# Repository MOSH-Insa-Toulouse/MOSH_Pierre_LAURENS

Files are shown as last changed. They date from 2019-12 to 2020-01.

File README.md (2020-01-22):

# Projet Smart Device
# MICRO-CONTROLEURS ET OPEN-SOURCE HARDWARE:
# Projet de Construction d'un capteur de gaz 
>LAURENS [Pierre](mailto:plaurens@etud.insa-toulouse.fr) - TOUZANI Ismail - Krishna Sujan

<a href="./README_EN.md">Version Anglaise</a>

Ce projet, faisant partie du Master 5ISS de l'INSA Toulouse, a été developpé dans le but de créer un capteur de gas intelligent capable de détecter plusieurs types de gas qui pourront être dangereux pour la santé humaine.
Après avoir construit le capteur dans l'atelier AIME de l'INSA, il sera donc nécessaire de le régler pour en extraire les informations utiles: cela se fera grâce au logiciel LTSpice IV pour la partie éléctronique analogique. Ensuite, et afin de récupérer les données du capteur et les communiquer à travers le réseau LoRA, on utilisera une carte Arduino Uno et une puce RN2483. Enfin, nous utiliserons le logiciel KiCAD pour effectuer le schéma adéquat du câblage entre les différents composants.

# Contenu du Projet
Le projet est constitué des répertoires suivants:
-   **Mosh (Arduino IDE)**: Contient les fichiers des tps effectués en utilisant l'IDE d'Arduino ainsi que les fichiers du projet.

-   **KiCAD**: Contient les fichiers nécessaires à la réalisation du PCB.
Ce fichier est composé de 3 dossiers.
    - **Projet Kicad** : contenant la première version de notre projet.
    - **Projet Kicad plan de masse** : contenant le même projet que le fichier ci-dessus mais avec la réalisation du plan de masse.
    - **Projet Kicad Aime plan de masse** : contenant le PCB du capteur de Gaz réalisé dans les locaux du AIME.

-   **LTSpice**: Contient les fichiers nécessaires à la partie éléctronique analogique.

-  **Manufacturing_Kicad**: Dossier contenant le fichier de création de la carte.

### Partie collection de données et communication LoRA: 
Dans cette partie, nous avons testé la collection de données et communication LoRA avec un capteur de test:

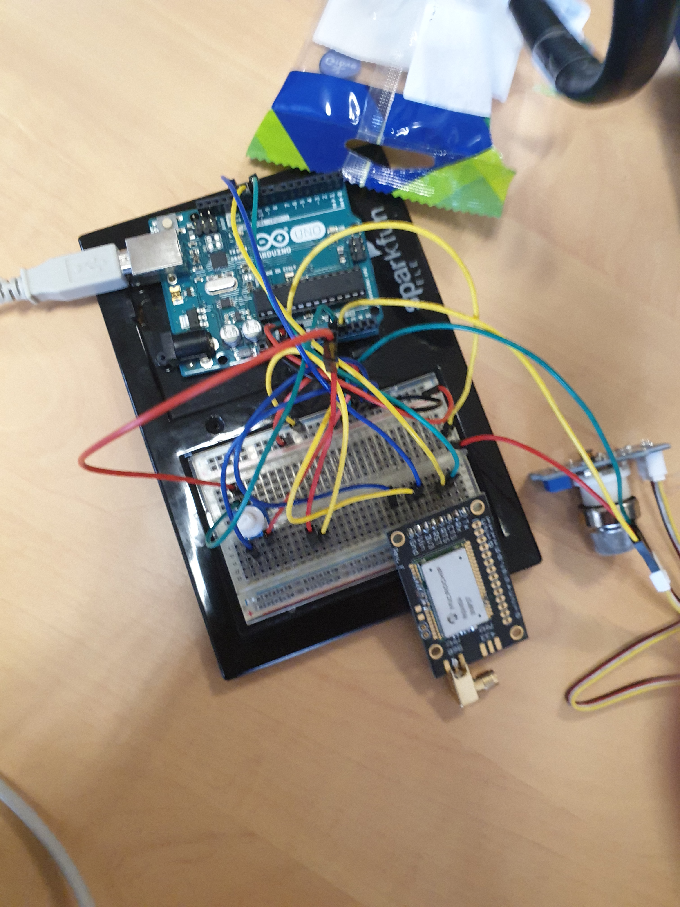
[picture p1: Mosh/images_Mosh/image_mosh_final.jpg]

Ci-dessus l'image du montage permettant d'interconnecter le module LoRa, l'Arduino UNO et le capteur de Gaz.
Ci-dessous une série d'images montrant le résultat de notre montage avec la réception et l'envoi de la valeur du capteur.

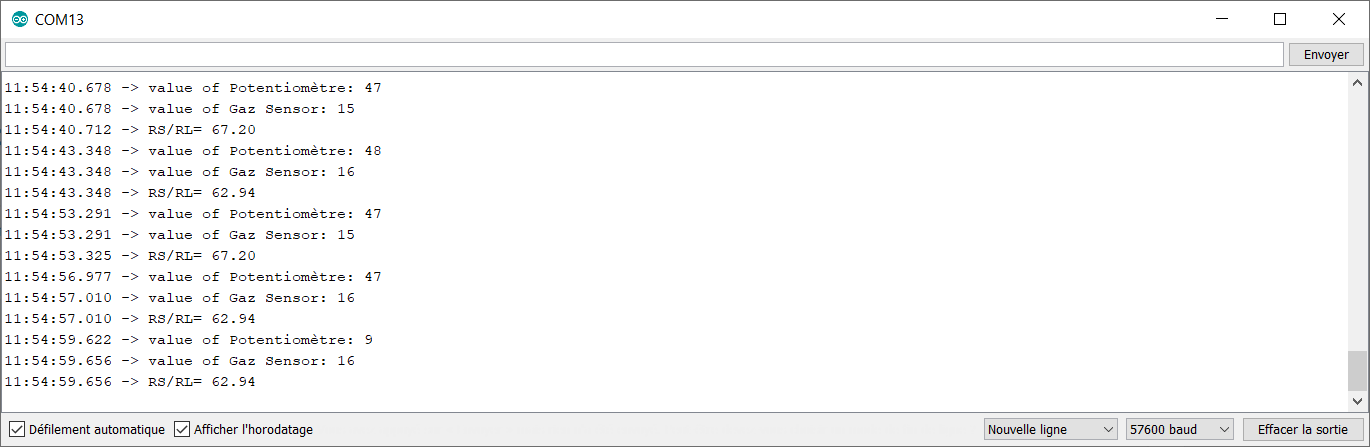
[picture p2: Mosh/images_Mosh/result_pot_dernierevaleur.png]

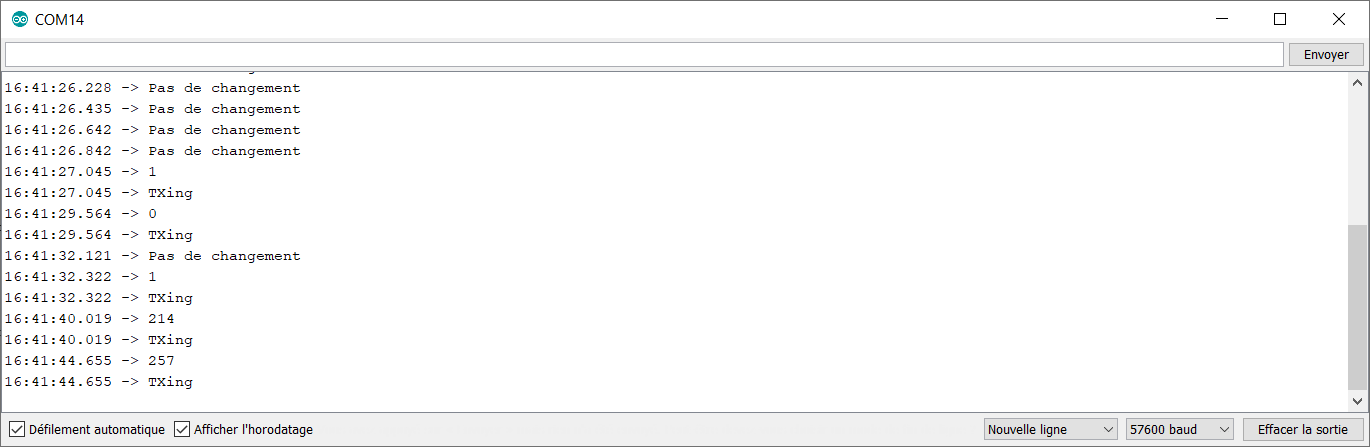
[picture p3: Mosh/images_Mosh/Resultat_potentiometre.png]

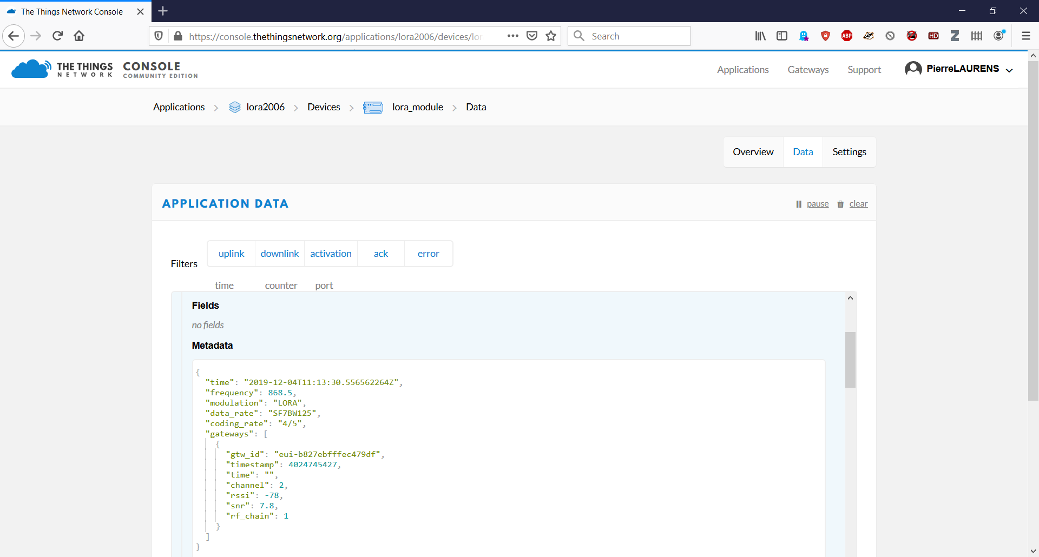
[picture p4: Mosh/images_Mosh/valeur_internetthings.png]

### Partie construction du shield/PCB: 
Dans cette partie, nous avons construit notre propre shield/PCB grâce à KiCAD :

Un Zoom sur la conception du capteur de Gaz AIME sur Eeschema:

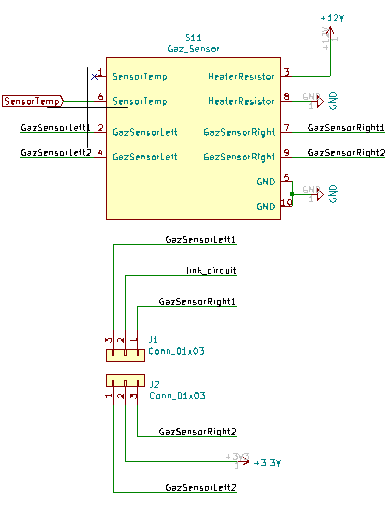
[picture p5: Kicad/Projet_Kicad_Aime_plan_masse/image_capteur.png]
Schéma électronique du capteur


Puis ci-dessous, l'ensemble du Capteur Intelligent designé sur Eeschema:

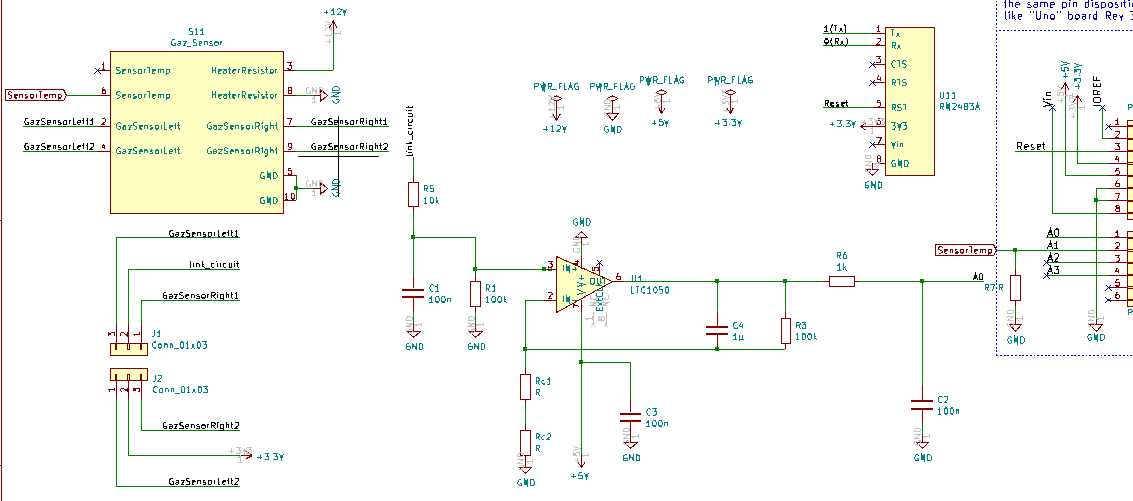
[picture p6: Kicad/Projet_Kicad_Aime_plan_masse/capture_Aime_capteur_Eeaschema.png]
Schéma électronique du capteur intelligent


Conception du layout avec le traçage des routes et la création des footprints et leur positionnement sur la carte.

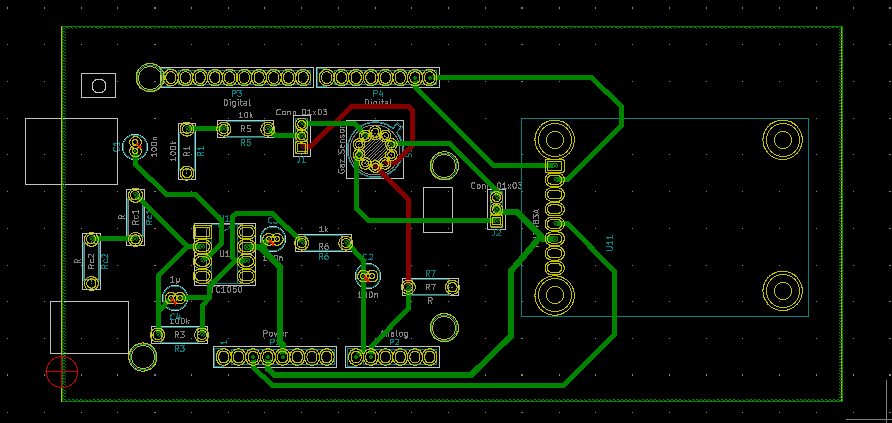
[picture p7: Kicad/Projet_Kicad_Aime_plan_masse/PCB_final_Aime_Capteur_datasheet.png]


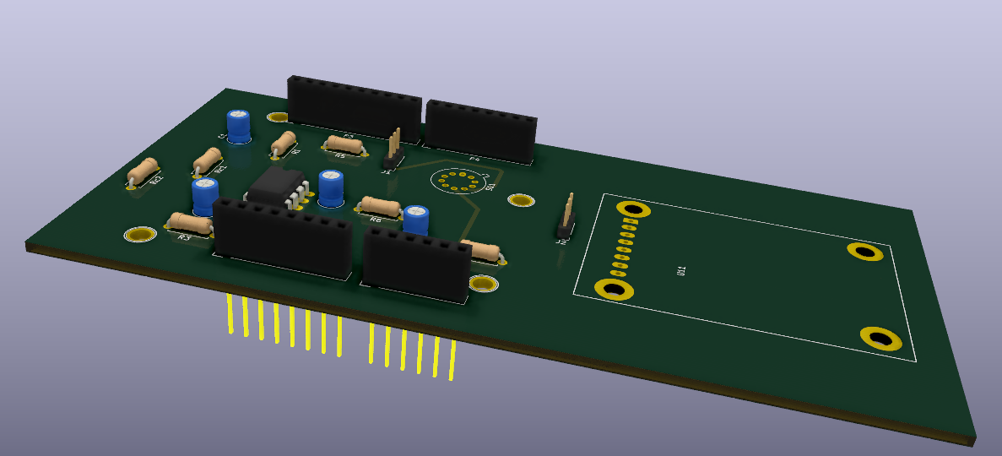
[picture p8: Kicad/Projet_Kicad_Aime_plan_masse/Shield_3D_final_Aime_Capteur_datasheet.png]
Schéma Shield Avant 3D


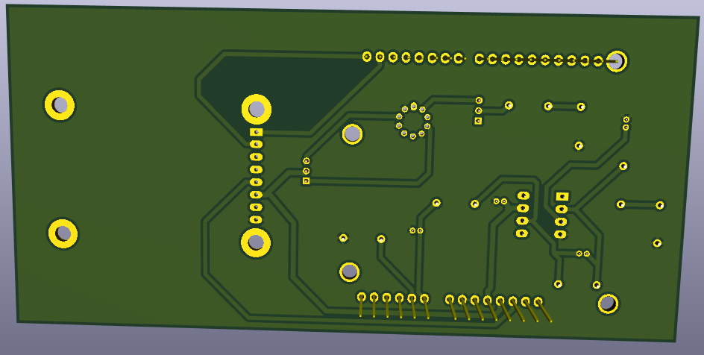
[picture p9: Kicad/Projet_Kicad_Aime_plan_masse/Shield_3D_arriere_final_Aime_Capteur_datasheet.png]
Schéma Shield Arrière 3D


Nous avons réalisé un plan de masse pour réduire la consommation en cuivre et limiter le routage en une seule couche. En effet, nous avons  supprimé toutes les routes sur la couche avant de notre shield(rouge) présentent sur la photo ci-dessus.
Le plan de masse permet également de réaliser le routage sur une seule couche, la couche arrière  de notre Shield. Pour finir, nous avons ainsi respecté les contraintes de routage définies par l'INSA.

### Partie électronique analogique: 
Concernant cette partie, nous avons étudier, en utilisant LTSPice IV, la partie électronique analogique du module Smart Device où nous serons amené à mesurer la résistance, le faible courant avec un microcontrôleur et effectuer un filtrage passe bas pour extraire les informations utiles de notre capteur de gaz. 

<a href="/LTspice/UF_Smart_Device_ Partie_analogique_avec_LTSpice_IV.pdf">Rapport_LTSPice</a>

### Choix de Conception

 - Nous avons modifié la forme du contour du shield en un rectangle plus grand que l'Arduino UNO pour faciliter le routage et l'inclusion de la puce LoRa.

- Au niveau du PCB, nous avons du faire face à des avertissements de type "Pad près d'un pad" au moment de la validation de notre PCB. Nous avons remarqué que ces messages ciblés les capacités que nous avons choisi dans les librairies génériques qui se sont avérés plus petites que ceux que nous utiliserons en réalité. Les marges de pistes sont trop épaisses par rapport à l'espacement entre les 2 broches des capacités provoquant un chevauchent de celles-ci entre elles. Pour changer cela, il faudrait choisir d'autres empreintes pour ces composants, car compte tenu des contraintes de fabrication qui nous sont imposées, nous ne pouvons pas réduire l'épaisseur des pistes). 

- Nous avons effectué tous les routage sur une seule couche de cuivre sur la carte pour rendre possible sa fabrication à l'INSA. Les pistes sont sur la partie "Bottom" qui est aussi le plan de masse. Les composants sont quand eux positionnés sur la partie "Top".

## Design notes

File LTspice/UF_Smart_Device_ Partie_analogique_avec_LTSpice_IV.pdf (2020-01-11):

## Introduction

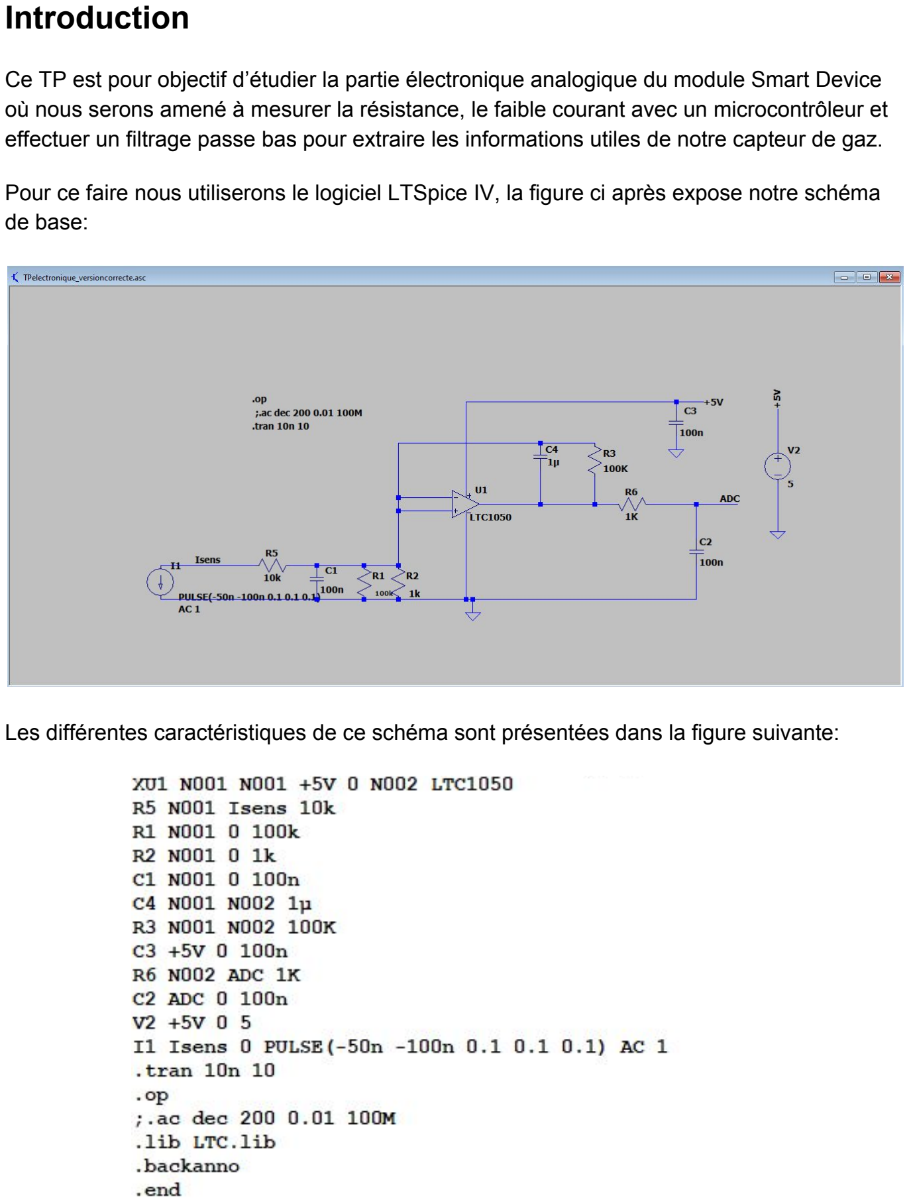
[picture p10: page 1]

Ce TP est pour objectif d’étudier la partie électronique analogique du module Smart Device où nous serons amené à mesurer la résistance, le faible courant avec un microcontrôleur et effectuer un filtrage passe bas pour extraire les informations utiles de notre capteur de gaz.

Pour ce faire nous utiliserons le logiciel LTSpice IV, la figure ci après expose notre schéma de base:

Les différentes caractéristiques de ce schéma sont présentées dans la figure suivante:

## Questions

1. Le montage amplifie bien avec un gain de ~100.

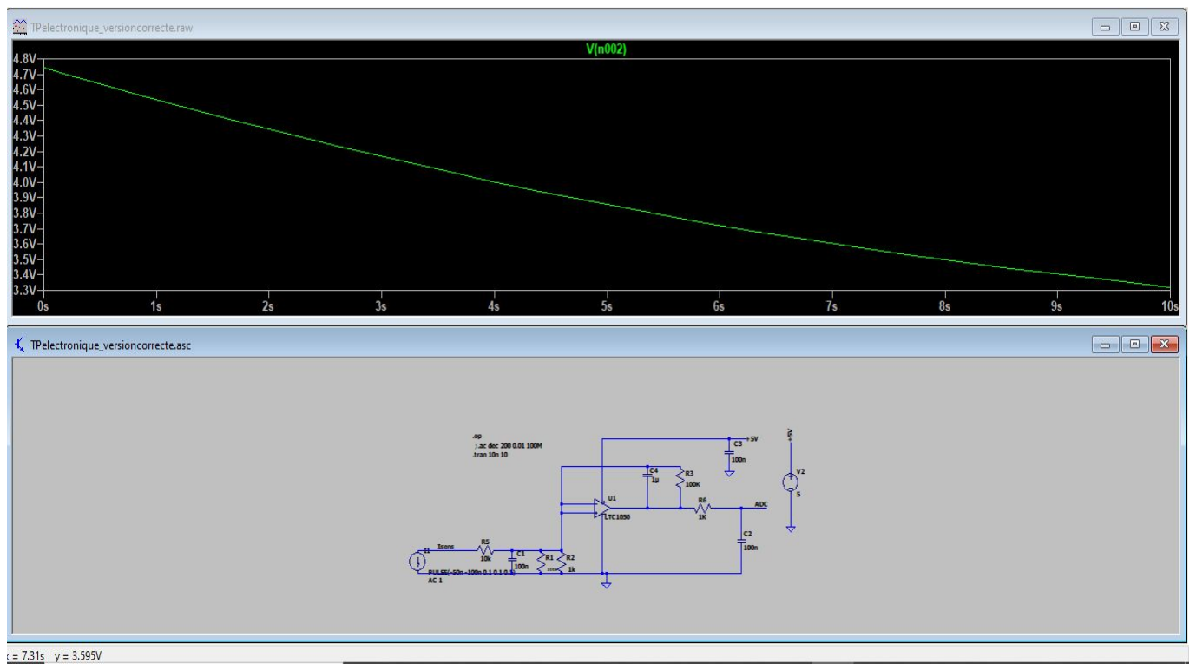
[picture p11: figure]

2. Avec un gain de 100, on a un offset de 0.5 mV en sortie, ce qui fait que l'on a une erreur minime de moins de 1 digit. En effet l'ADC a une précision sur 12 bits, ce qui fait 5/4096 ~1.2 mV.
3. L'incidence du courant d'entrée est de 1.8 fA/sqrt(Hz) soit pour un signal de l'ordre du Hz on a 1,8.10^(-15) << 10^(-9)
4. Les fréquences de coupure correspondantes à chaque étage sont:
4.1. Étage 1 : fc = 1/(2π*1*10^(-7)*1*10^5 ) = 15.92 Hz
4.2. Étage 2 : fc = 1 /(2π*1*10^(-6)*1*10^5)= 1.59 Hz
4.3. Étage 3 : fc = 1 /(2π*1*10^(-7)*1*10^3)= 1.59 kHz
5. L’atténuation globale d'un bruit en courant de 50 Hz est de 40dB.

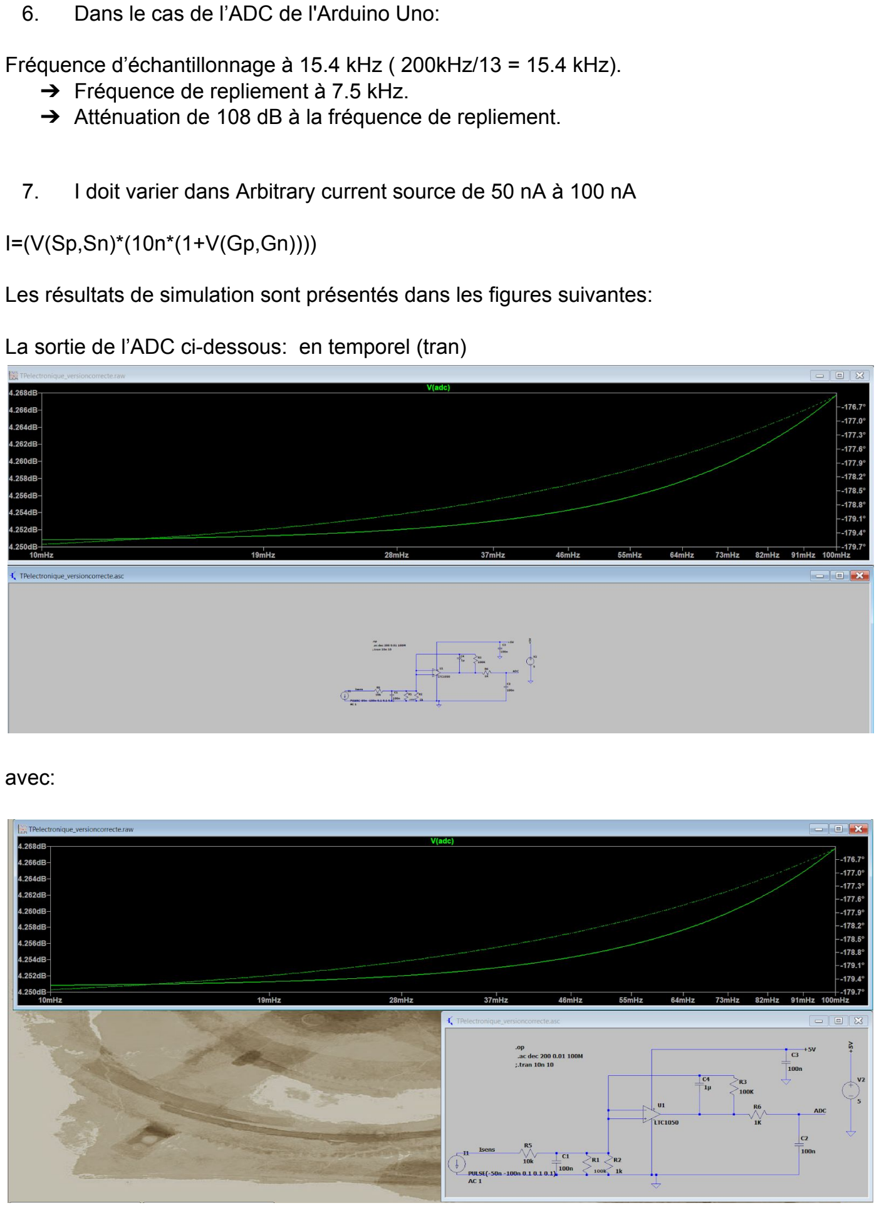
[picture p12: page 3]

6. Dans le cas de l’ADC de l'Arduino Uno:

Fréquence d’échantillonnage à 15.4 kHz ( 200kHz/13 = 15.4 kHz). ➔ Fréquence de repliement à 7.5 kHz.
➔ Atténuation de 108 dB à la fréquence de repliement.
7. I doit varier dans Arbitrary current source de 50 nA à 100 nA

I=(V(Sp,Sn)*(10n*(1+V(Gp,Gn))))

Les résultats de simulation sont présentés dans les figures suivantes:

La sortie de l’ADC ci-dessous: en temporel (tran)

avec:

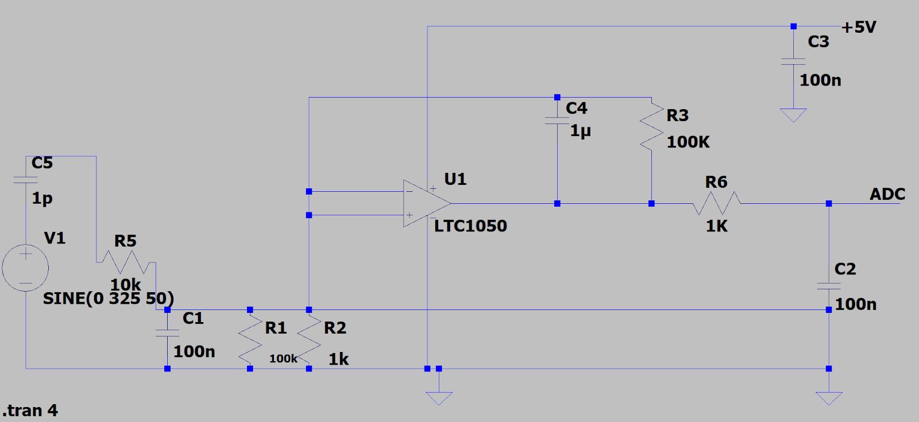
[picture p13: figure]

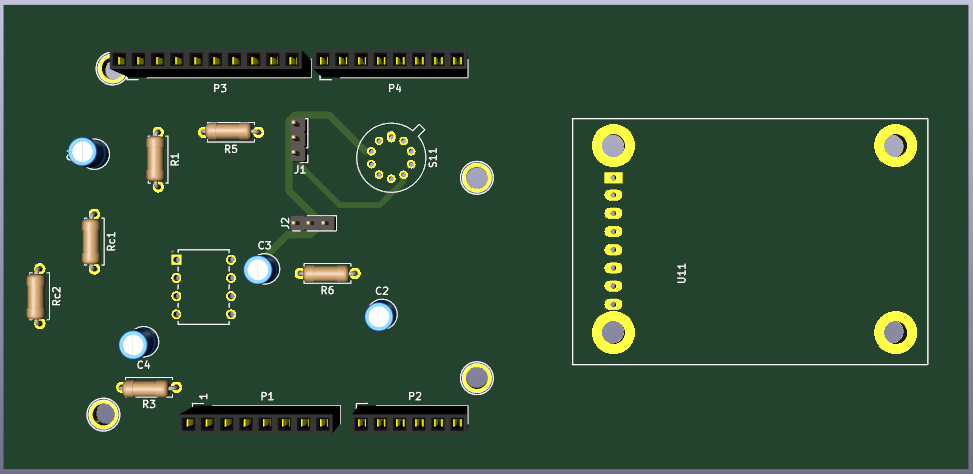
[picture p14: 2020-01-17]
Kicad/Projet_Kicad_Aime_plan_masse/PcB_Aime_Sensor.png

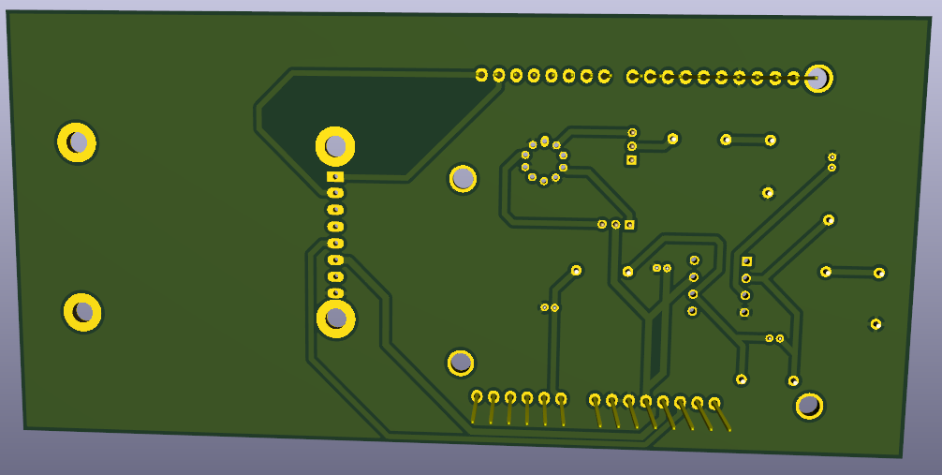
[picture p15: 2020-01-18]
Kicad/Projet_Kicad_Aime_plan_masse/PcB_Aime_Shield_arriere_3D.png

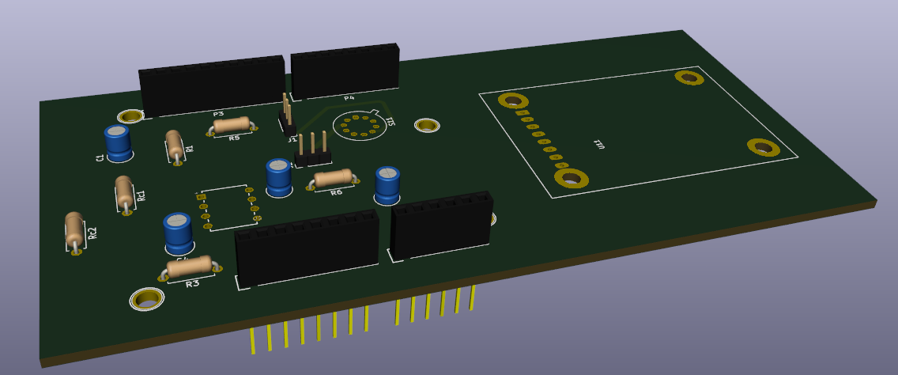
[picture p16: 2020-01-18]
Kicad/Projet_Kicad_Aime_plan_masse/PcB_Aime_Sensor_2.png

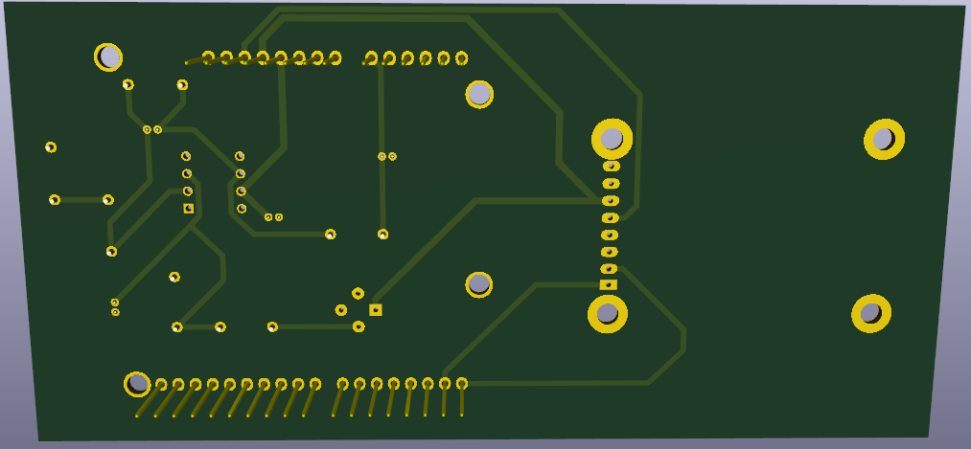
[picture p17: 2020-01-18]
Kicad/Projet_Kicad/Shield_arriere_3D.png

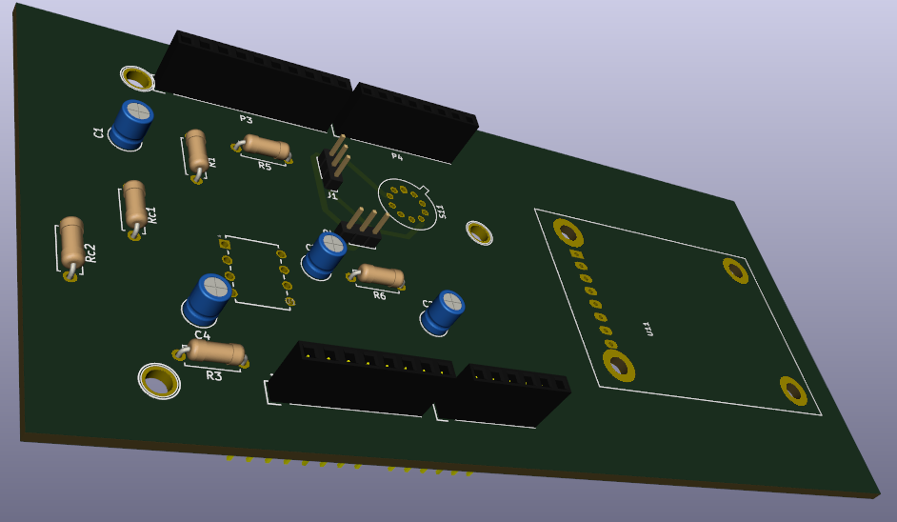
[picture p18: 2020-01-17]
Kicad/Projet_Kicad_Aime_plan_masse/Sensor_Aime_shield_3D.png

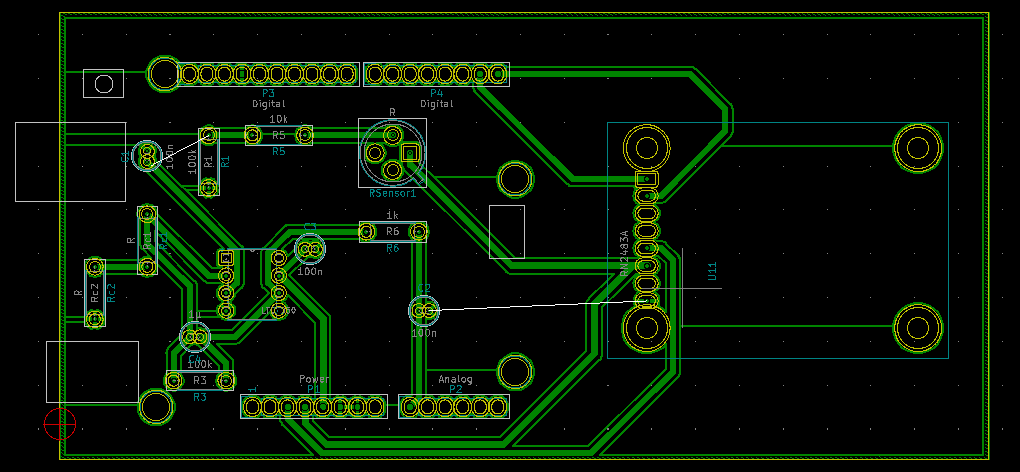
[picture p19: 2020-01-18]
Kicad/Projet_Kicad_plan_masse/Kicad_plan_masse.png

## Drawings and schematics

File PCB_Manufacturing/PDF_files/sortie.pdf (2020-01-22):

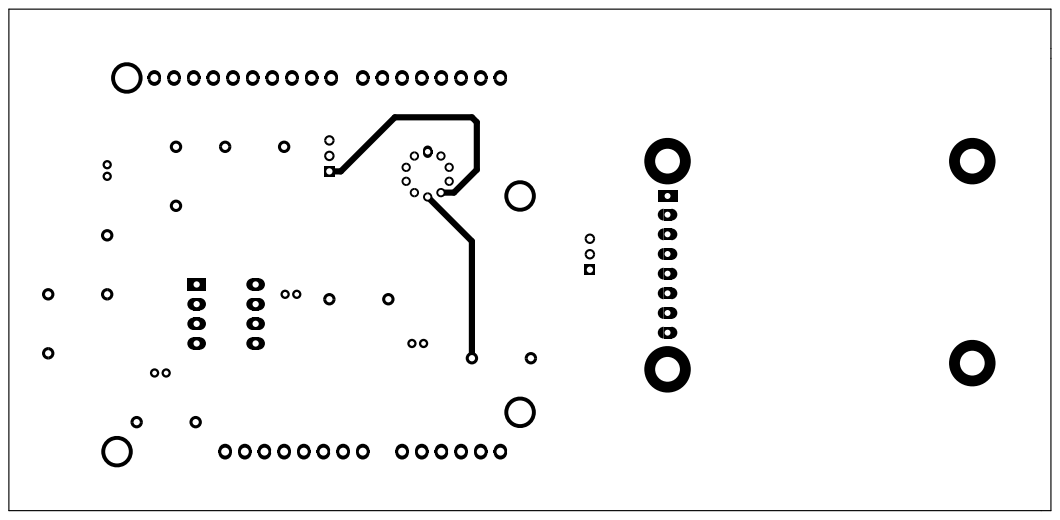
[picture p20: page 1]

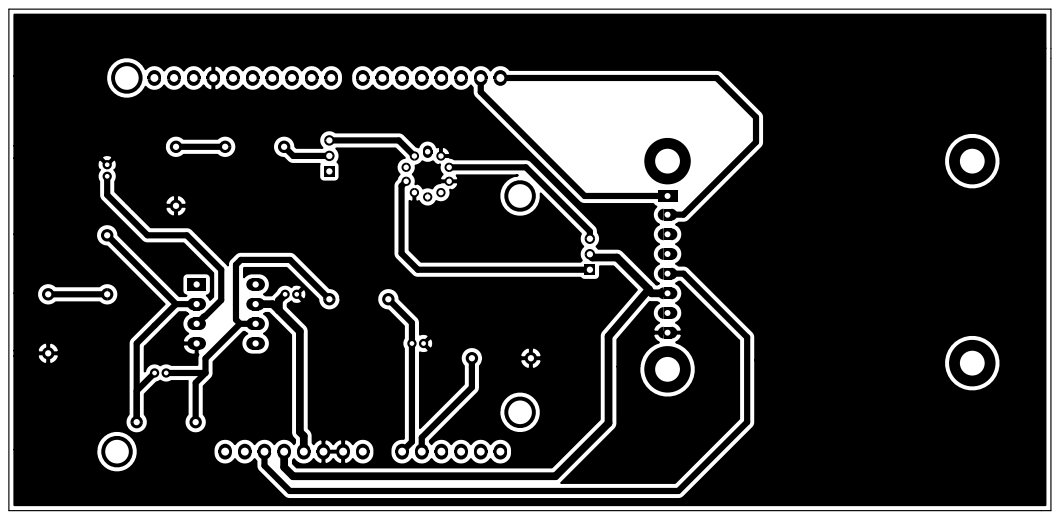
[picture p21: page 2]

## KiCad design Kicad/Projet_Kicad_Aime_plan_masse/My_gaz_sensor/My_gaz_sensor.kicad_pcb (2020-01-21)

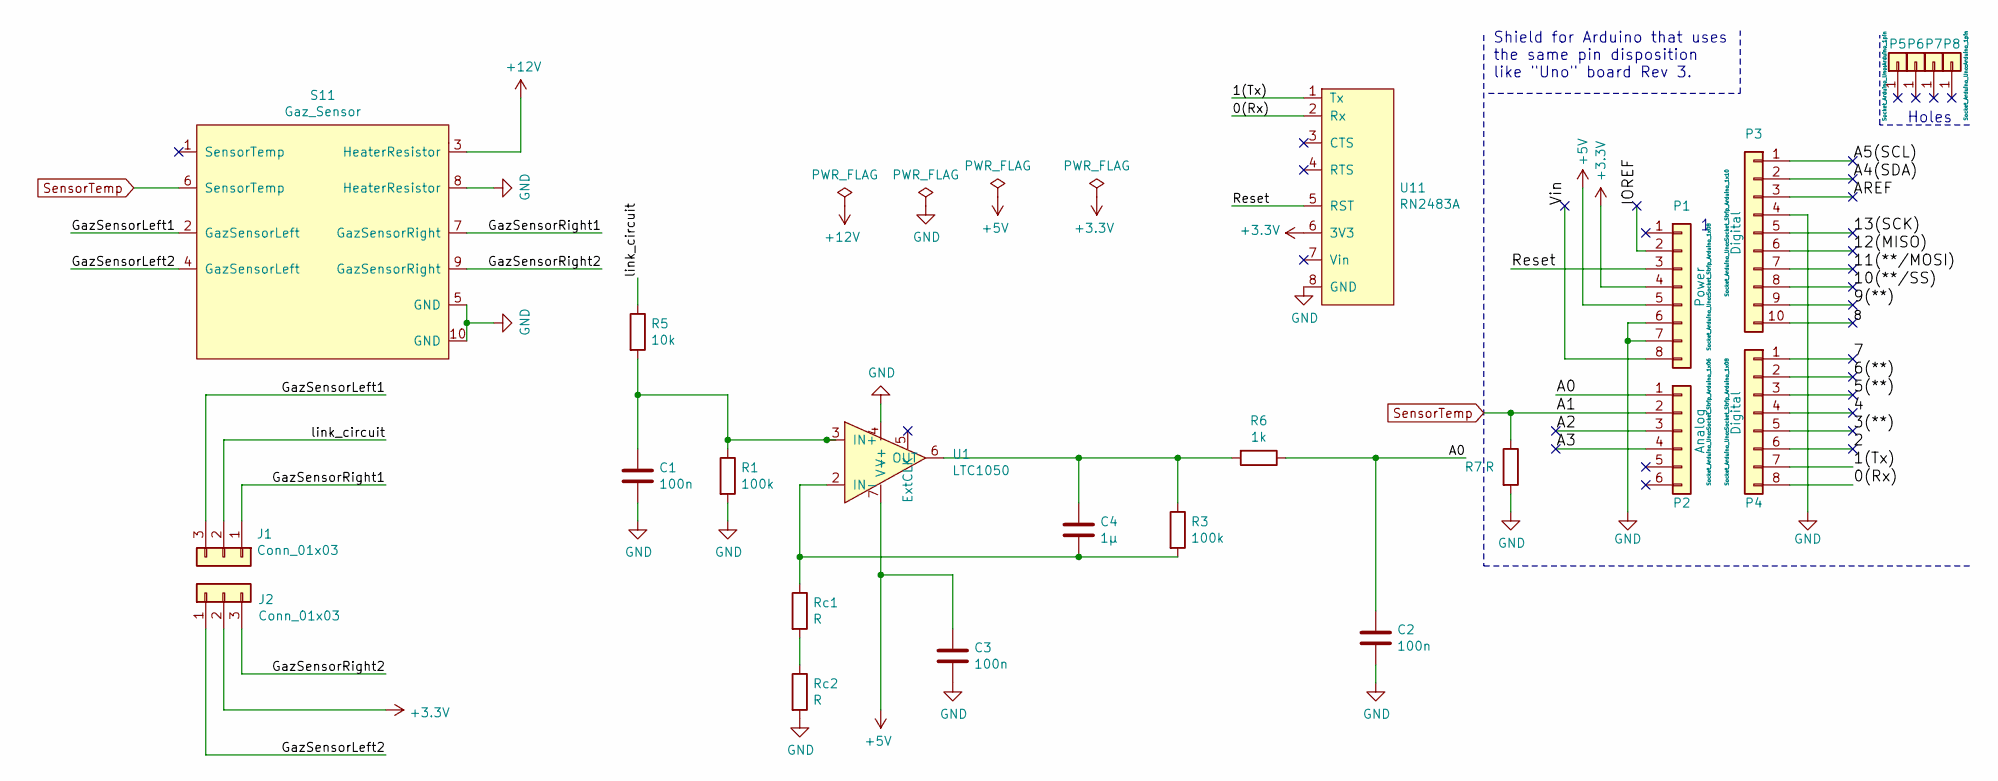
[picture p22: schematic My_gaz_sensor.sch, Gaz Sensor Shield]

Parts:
C1, C2, C3: 100n; C_Radial_D4.0mm_H5.0mm_P1.50mm
C4: 1µ; C_Radial_D4.0mm_H5.0mm_P1.50mm
J1, J2: Conn_01x03; PinHeader_1x03_P2.00mm_Vertical
P1: Power; Socket_Strip_Arduino_1x08
P2: Analog; Socket_Strip_Arduino_1x06
P3: Digital; Socket_Strip_Arduino_1x10
P4: Digital; Socket_Strip_Arduino_1x08
P5, P6, P7, P8: CONN_01X01; Arduino_1pin
R1, R3: 100k; R_Axial_DIN0207_L6.3mm_D2.5mm_P7.62mm_Horizontal
R5: 10k; R_Axial_DIN0207_L6.3mm_D2.5mm_P7.62mm_Horizontal
R6: 1k; R_Axial_DIN0207_L6.3mm_D2.5mm_P7.62mm_Horizontal
R7: R; R_Axial_DIN0207_L6.3mm_D2.5mm_P7.62mm_Horizontal
Rc1, Rc2: R; R_Axial_DIN0207_L6.3mm_D2.5mm_P7.62mm_Horizontal
S11: Gaz_Sensor; TO-5-10_Window
U1: LTC1050; DIP-8_W7.62mm_LongPads
U11: RN2483A; RN2483_Breakout

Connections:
+3V3: J2.2, P1.4, U11.6 (3V3)
+5V: C3.1, P1.5, U1.7 (V-)
+12V: S11.3 (HeaterResistor)
/0(Rx): P4.8, U11.2 (Rx)
/1(Tx): P4.7, U11.1 (Tx)
/2: P4.6
/3(**): P4.5
/4: P4.4
/5(**): P4.3
/6(**): P4.2
/7: P4.1
/8: P3.10
/9(**): P3.9
/10(**/SS): P3.8
/11(**/MOSI): P3.7
/12(MISO): P3.6
/13(SCK): P3.5
/A0: C2.1, P2.1, R6.1
/A2: P2.3
/A3: P2.4
/A4(SDA): P3.2
/A5(SCL): P3.1
/AREF: P3.3
/GazSensorLeft1: J1.3, S11.2 (GazSensorLeft)
/GazSensorLeft2: J2.1, S11.4 (GazSensorLeft)
/GazSensorRight1: J1.1, S11.7 (GazSensorRight)
/GazSensorRight2: J2.3, S11.9 (GazSensorRight)
/IOREF: P1.2
/Reset: P1.3, U11.5 (RST)
/Vin: P1.8
/link_circuit: J1.2, R5.1
GND: C1.2, C2.2, C3.2, P1.6, P1.7, P3.4, R1.2, R7.2, Rc2.2, S11.5 (GND), S11.8 (HeaterResistor), S11.10 (GND), U1.4 (V+), U11.8 (GND)
unnamed: C1.1, R1.1, R5.2, U1.3 (IN+)
unnamed: C4.1, R3.1, R6.2, U1.6 (OUT)
unnamed: C4.2, R3.2, Rc1.1, U1.2 (IN-)
unnamed: Rc1.2, Rc2.1
SensorTemp: P2.2, R7.1, S11.6 (SensorTemp)

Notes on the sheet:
Holes
Shield for Arduino that uses the same pin disposition like "Uno" board Rev 3.

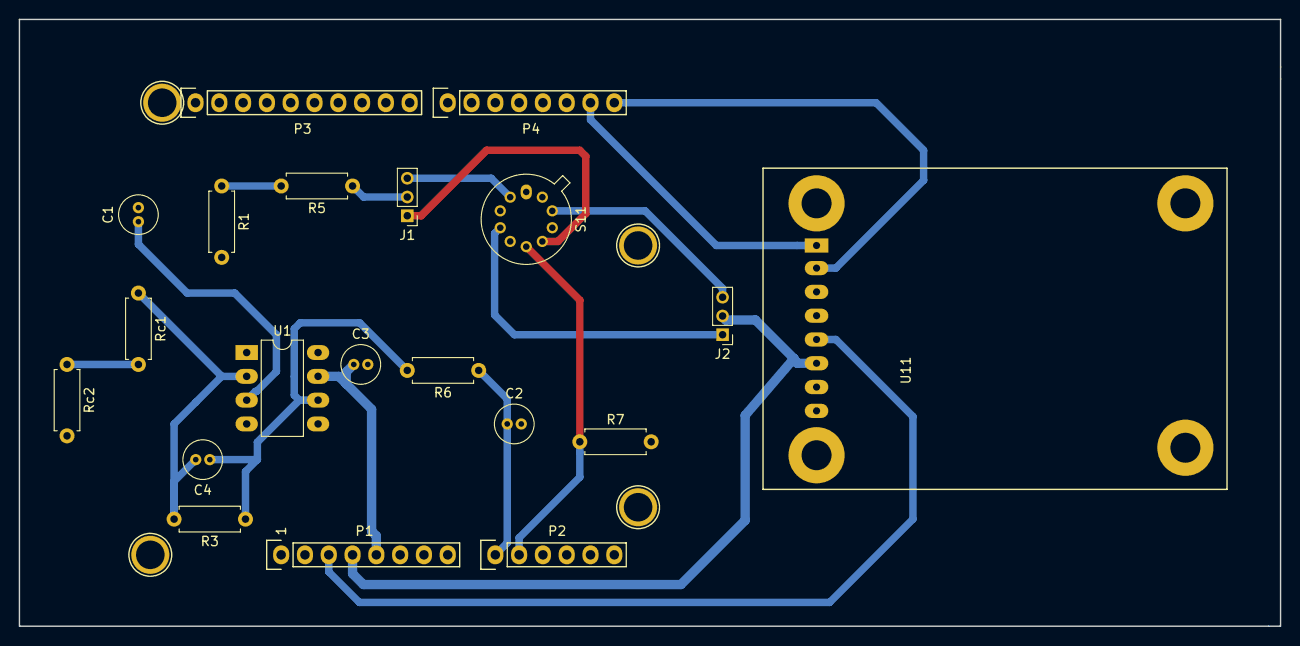
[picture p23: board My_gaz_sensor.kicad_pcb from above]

Board: 2 copper layers, 134.6 x 64.8 mm, 24 parts (0 on the bottom side), 17 nets.

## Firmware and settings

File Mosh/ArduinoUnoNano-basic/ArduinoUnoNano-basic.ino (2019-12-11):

/*
 * Author: JP Meijers
 * Date: 2016-02-07
 * Previous filename: TTN-Mapper-TTNEnschede-V1
 *
 * This program is meant to be used with an Arduino UNO or NANO, conencted to an RNxx3 radio module.
 * It will most likely also work on other compatible Arduino or Arduino compatible boards, like The Things Uno, but might need some slight modifications.
 *
 * Transmit a one byte packet via TTN. This happens as fast as possible, while still keeping to
 * the 1% duty cycle rules enforced by the RN2483's built in LoRaWAN stack. Even though this is
 * allowed by the radio regulations of the 868MHz band, the fair use policy of TTN may prohibit this.
 *
 * CHECK THE RULES BEFORE USING THIS PROGRAM!
 *
 * CHANGE ADDRESS!
 * Change the device address, network (session) key, and app (session) key to the values
 * that are registered via the TTN dashboard.
 * The appropriate line is "myLora.initABP(XXX);" or "myLora.initOTAA(XXX);"
 * When using ABP, it is advised to enable "relax frame count".
 *
 * Connect the RN2xx3 as follows:
 * RN2xx3 -- Arduino
 * Uart TX -- 10
 * Uart RX -- 11
 * Reset -- 12
 * Vcc -- 3.3V
 * Gnd -- Gnd
 *
 * If you use an Arduino with a free hardware serial port, you can replace
 * the line "rn2xx3 myLora(mySerial);"
 * with     "rn2xx3 myLora(SerialX);"
 * where the parameter is the serial port the RN2xx3 is connected to.
 * Remember that the serial port should be initialised before calling initTTN().
 * For best performance the serial port should be set to 57600 baud, which is impossible with a software serial port.
 * If you use 57600 baud, you can remove the line "myLora.autobaud();".
 *
 */
#include <rn2xx3.h>
#include <SoftwareSerial.h>

//définition des PINs
#define potentiometrePin A0
#define GazSensorPin A1

//initialisation de la valeur du potentiometre
int Pot;
int Pot_ancienne = 0;
int GazSensor;

//Initialisation de la led
int led=13;
//Initialisation de la variable de la led qui permet d'envoyer le bon rapport cyclique à la led
int val_led;

SoftwareSerial mySerial(10, 11); // RX, TX

//create an instance of the rn2xx3 library,
//giving the software serial as port to use
rn2xx3 myLora(mySerial);

// the setup routine runs once when you press reset:
void setup()
{
  //output LED pin
  pinMode(13, OUTPUT);
  led_on();

  pinMode(potentiometrePin, INPUT);
  pinMode(GazSensorPin, INPUT);

  //attachInterrupt(0, envoiData, RISING); 

  // Open serial communications and wait for port to open:
  Serial.begin(57600); //serial port to computer
  mySerial.begin(9600); //serial port to radio
  Serial.println("Startup");

  initialize_radio();

  //transmit a startup message
  myLora.tx("TTN Mapper on TTN Enschede node");

  led_off();
  delay(20);
}

/*int envoiData(int Pot, int Pot_ancienne, int led, int val_led){
  if((Pot_ancienne > Pot+10) || (Pot_ancienne < Pot-10)){
    Serial.println(Pot);  
    led_on();
    myLora.tx(Pot); //one byte, blocking function
    //val_led = map(Pot,0,1023,0,255);
    led_off();    
    analogWrite(led, val_led);    
    Pot_ancienne = Pot;
  }else{
     Serial.println("Pas de changement");
  }
  return Pot_ancienne;
  
}*/

void initialize_radio()
{
  //reset rn2483
  pinMode(12, OUTPUT);
  digitalWrite(12, LOW);
  delay(500);
  digitalWrite(12, HIGH);

  delay(1000); //wait for the RN2xx3's startup message
  mySerial.flush();

  //Autobaud the rn2483 module to 9600. The default would otherwise be 57600.
  myLora.autobaud();

  //check communication with radio
  String hweui = myLora.hweui();
  while(hweui.length() != 16)
  {
    Serial.println("Communication with RN2xx3 unsuccessful. Power cycle the board.");
    Serial.println(hweui);
    delay(10);
    hweui = myLora.hweui();
  }

  //print out the HWEUI so that we can register it via ttnctl
  Serial.println("When using OTAA, register this DevEUI: ");
  Serial.println(myLora.hweui());
  Serial.println("RN2xx3 firmware version:");
  Serial.println(myLora.sysver());

  //configure your keys and join the network
  Serial.println("Trying to join TTN");
  bool join_result = false;


  /*
   * ABP: initABP(String addr, String AppSKey, String NwkSKey);
   * Paste the example code from the TTN console here:
   */
const char *devAddr = "26011665";
const char *nwkSKey = "6ECAEDF845E8EA3E0E81F46263669E23";
const char *appSKey = "EBFE16A516BEEF67041441D99B0E70D5";

  join_result = myLora.initABP(devAddr, appSKey, nwkSKey);

  /*
   * OTAA: initOTAA(String AppEUI, String AppKey);
   * If you are using OTAA, paste the example code from the TTN console here:
   */
  //const char *appEui = "70B3D57ED00001A6";
  //const char *appKey = "A23C96EE13804963F8C2BD6285448198";

  //join_result = myLora.initOTAA(appEui, appKey);


  while(!join_result)
  {
    Serial.println("Unable to join. Are your keys correct, and do you have TTN coverage?");
    delay(60000); //delay a minute before retry
    join_result = myLora.init();
  }
  Serial.println("Successfully joined TTN");

}

// the loop routine runs over and over again forever:
void loop()
{
    // Lire la valeur du potentiomètre
    int Pot = analogRead(potentiometrePin);
    delay(100);
    int GazSensor= analogRead(GazSensorPin);

    //fonction qui gère l'envoi que si 
    //Pot_ancienne = envoiData(Pot, Pot_ancienne, led, val_led);  
    char str[4];
    str[0] =(Pot >> 8) & 0xFF;
    str[1] = Pot & 0xFF;
    str[2] = (GazSensor >> 8) & 0xFF;
    str[3] = GazSensor & 0xFF;

    Serial.print("value of Potentiomètre: ");
    Serial.println(Pot);
    Serial.print("value of Gaz Sensor: ");
    Serial.println(GazSensor);
    Serial.print("RS/RL= ");
    Serial.println((float)(1023-GazSensor)/GazSensor);

    myLora.txBytes(str, sizeof(str));
    
    delay(200);
}

void led_on()
{
  digitalWrite(13, 1);
}

void led_off()
{
  digitalWrite(13, 0);
}

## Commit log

2020-01-11 Refactor of the content - Add PCB-KICAD&MOSH
    [My_gaz_sensor.kicad_pcb, My_gaz_sensor.sch]
2020-01-11 Kicad plan de masse et Maj Readme
    [My_gaz_sensor.kicad_pcb, My_gaz_sensor.sch]
2020-01-11 Ajout de la Partie électronique
2020-01-13 Modification: MàJ du dossier "Kicad"
    [My_gaz_sensor.kicad_pcb, My_gaz_sensor.sch]
2020-01-17 Kicad Project with AIME Gaz Sensor
    [My_gaz_sensor.kicad_pcb, My_gaz_sensor.sch]
2020-01-17 Add Pictures Aime sensor
2020-01-18 Refactor valeur C4
    [My_gaz_sensor.kicad_pcb, My_gaz_sensor.sch]
2020-01-18 MàJ des README FR et EN
2020-01-18 Refactor eschema capteur Gaz Aime
    [My_gaz_sensor.sch]
2020-01-18 Reduction des near-to-pad
    [My_gaz_sensor.kicad_pcb]
2020-01-19 Changement pour s'adapter à la datasheet
    [My_gaz_sensor.kicad_pcb]
2020-01-21 Refactor Aime Kicad Part
    [My_gaz_sensor.kicad_pcb, My_gaz_sensor.sch]
